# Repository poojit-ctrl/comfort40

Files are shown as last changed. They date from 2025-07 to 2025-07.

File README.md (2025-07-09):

# Comfort40

Comfort40 is a compact 40-key mechanical keyboard designed to ditch all the bloat and keep only what matters. It’s got the vibe of minimalism with just enough muscle to handle your everyday typing, coding, shortcut-spamming, and layer-fu. Built for chill, built for speed, built for the desk setups that scream “I know what I’m doing.”



---

## What Even Is This

Comfort40 is a DIY keyboard project for anyone who’s ever looked at a full-size keyboard and thought “nah.” It’s a 40% board, ortholinear (so all the keys line up like a grid), and completely open source. You can build it however you like solder or hotswap, loud clicky switches or silent stealthy ones. It’s your call.

This board runs QMK and VIA, so you can customize literally every key. Layer keys? Macro madness? Tap dance? Yeah, it’s all here. Want a numpad? Put it on a layer. Arrows? You bet. The layout may be tiny but the power is unhinged.

---

## The Vibe

Comfort40 is designed in KiCad, modeled in Fusion 360, and 100% meant to be hacked on. The case is 3D printable, the plate is laser cuttable.
---

## Build Stats

layout → 4x10 grid  
switches → MX-style 
controller → RP2040  
port → USB-C  
pcb → hotswap  
NO RGB THO  
case → printable 
firmware → QMK + VIA

---
| Component | Description | Qty | Estimated Price (USD) | Notes |
|---|---|-----|---|---|
| **PCB** | Custom Comfort40 PCB | 1 | $30.00(after coupon) | From JLCPCB or similar |
| **Microcontroller** | RP2040 | 1 | $2.00 | USB-C |
| **Switches** | MX-compatible mechanical switches | 40  | $20.00 | Gateron|
| **Keycaps** | 40-key ortholinear set | 1 | $23.00 | XDA/DSA works well |
| **Diodes** | 1N4148 | 40  | $3.00 | Through-hole or SMD |
| **Reset Switch** | Tactile momentary switch | 1 | $0.50 | Used for flashing |
| **Hotswap Sockets** | Kailh MX hotswap sockets | 40  | $8.00 | Why not |
| **Plate** | Laser-cut acrylic or FR4 | 1 | $6.00 | DXF included |
| **Case (Top + Bottom)** | 3D printed or resin enclosure | 1 | $18.00 | Print or outsource |
| **Screws/Standoffs** | M3 hardware | 1 set | $2.00 | For mounting everything |
| **USB Cable** | USB-C to USB-A cable | 1 | $4.00 | Any decent one |
| **Rotary Encoder** | EC11 vertical rotary encoder | 1 | $2.00 | Includes push button switch |
| **Knob Cap** | Aluminum or plastic vertical knob | 1 | $1.50 | Press-fit or set screw type |
| **Foam/Dampening** | EVA foam or PE sheet | 1 | ALREADY HAVE IT AT HOME| silencing mod |

---
## Estimated Total: **$120.00 USD**

## Images

## Fully Assembled Render  
| Image | Description |
|---|---|
| fully assembled render | A render straight outta Fusion 360. You’re looking at the full Comfort40 in all its glory, keycaps and all. |

## PCB  
| Image | Description |
|---|---|
| pcb | KiCad PCB layout. Shows the switch footprint grid, MCU spot, USB traces, and that crispy clean diode matrix. |

## Schematic  
| Image | Description |
|---|---|
| schematic | The full wiring brain. Every connection from switch to controller. Diodes, resistors, reset, and the rest. |

## KiCad 3D View  
| Image | Description |
|---|---|
| 3dview | The raw KiCad 3D preview. Check that switch layout and component placement. No case here, just vibes. |

## Hot swappable
| Image | Description |
|---|---|
|  | KLE Layout |

---

## Flashing the Brain

QMK is the default brain of Comfort40. Flash it with QMK Toolbox or VIA Configurator

---

## Who It’s For

- people who like small keyboards  
- people who like building stuff  
- people who hate reaching for arrow keys  
- people who want full power in a tiny square of plastic  
- also people who just want a reason to use their soldering iron again

---

## Licence

MIT

made for comfort not clutter  
zero bloat  
just keys

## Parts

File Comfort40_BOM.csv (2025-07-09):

Component | Description | Qty | Estimated Price (USD) | Notes
PCB | Custom Comfort40 PCB | 1 | 30 | From JLCPCB or similar
Microcontroller | RP2040 | 1 | 2 | USB-C
Switches | MX-compatible mechanical switches | 40 | 20 | Gateron
Keycaps | 40-key ortholinear set | 1 | 23 | XDA/DSA works well
Diodes | 1N4148 | 40 | 3 | Through-hole or SMD
Reset Switch | Tactile momentary switch | 1 | 0.5 | Used for flashing
Hotswap Sockets | Kailh MX hotswap sockets | 40 | 8 | Why not
Plate | Laser-cut acrylic or FR4 | 1 | 6 | DXF included
Case (Top + Bottom) | 3D printed or resin enclosure | 1 | 18 | Print or outsource
Screws/Standoffs | M3 hardware | 1 set | 2 | For mounting everything
USB Cable | USB-C to USB-A cable | 1 | 4 | Any decent one
Rotary Encoder | EC11 vertical rotary encoder | 1 | 2 | Includes push button switch
Knob Cap | Aluminum or plastic vertical knob | 1 | 1.5 | Press-fit or set screw type
Foam/Dampening | EVA foam or PE sheet | 1 | AVAILABLE | Optional silencing mod
 |  |  | $120.00

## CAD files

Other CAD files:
Case(f360 and step)/comfort40final.f3d

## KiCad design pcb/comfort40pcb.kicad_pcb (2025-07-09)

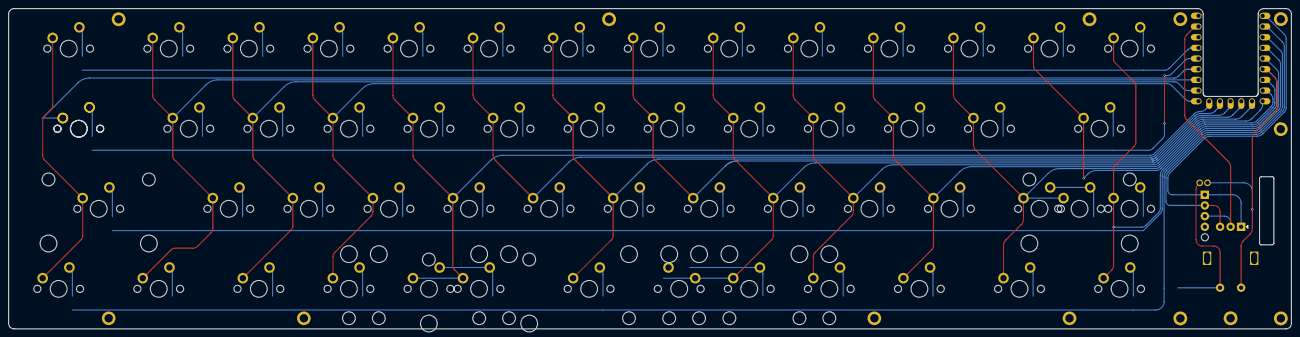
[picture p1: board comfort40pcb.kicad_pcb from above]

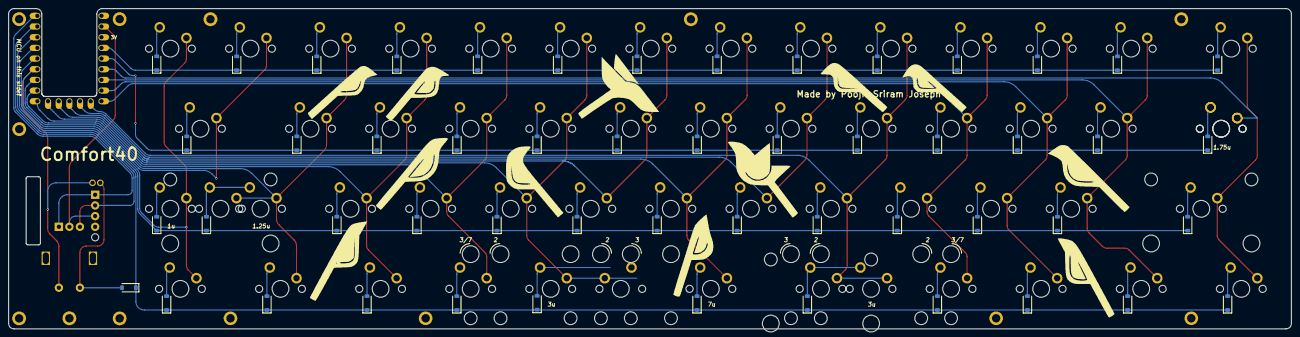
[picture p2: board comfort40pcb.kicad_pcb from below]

Board: 2 copper layers, 305.2 x 76.2 mm, 113 parts (52 on the bottom side), 73 nets.

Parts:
D1, D2, D3, D4, D5, D6, D7, D8, D9, D10, D11, D12, D13, D14, D15, D16, D17, D18, D19, D20, D21, D22, D23, D24, D25, D26, D27, D28, D29, D30, D31, D32, D33, D34, D35, D36, D37, D38, D39, D40, D41, D42, D43, D44, D45, D46, D47, D48, D49, D50, D51, D52: 1N4148W; D_SOD-123
MP: (no value)
SW1: MX150
SW2, SW3#2, SW4, SW5, SW6, SW7, SW8, SW9, SW10, SW11, SW12, SW13, SW14, SW16, SW17, SW18, SW19, SW20, SW21, SW22, SW23, SW24, SW25, SW26, SW29, SW30, SW31, SW32, SW33, SW34, SW35, SW36, SW37, SW38, SW45, SW50: MX100
SW3: Rotary_Encoder_Switch; EVQWGD001
SW15: Stepped; MX175
SW27: MX175
SW28: MX225R; MX225
SW39: 1.25u; MX125
SW40, SW47: 2.25u; MX225
SW41: 1u; MX100
SW42, SW43, SW44, SW51, SW52, SW53: MX125
SW46, SW49: 3u; MX300R
SW48: 7u; MX100
SW54: 2.75u; MX275R
SW55: RotaryEncoder_Switch; RotaryEncoder_Alps_EC11E-Switch_Vertical_H20mm
SW55#2: 1.75u; MX175
SW**: MX200R
SW**#2: MX200R
U1: RP2040-Zero; MCU_rp2040-zero-tht

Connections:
COL0: SW1.2 (Row), SW15.2 (Row), SW28.2 (Row), SW42.2 (Row), SW55#2.2
COL1: SW2.2 (Row), SW16.2 (Row), SW29.2 (Row), SW43.2 (Row)
COL2: SW3#2.2 (Row), SW17.2 (Row), SW30.2 (Row), SW44.2 (Row), U1.15
COL3: SW4.2 (Row), SW18.2 (Row), SW31.2 (Row), SW45.2 (Row), U1.14
COL4: SW5.2 (Row), SW19.2 (Row), SW32.2 (Row), SW46.2 (Row), SW47.2 (Row), U1.13
COL5: SW6.2 (Row), SW20.2 (Row), SW33.2 (Row), U1.12
COL6: SW7.2 (Row), SW21.2 (Row), SW34.2 (Row), SW48.2 (Row), U1.11
COL7: SW8.2 (Row), SW22.2 (Row), SW35.2 (Row), U1.10
COL8: SW9.2 (Row), SW23.2 (Row), SW36.2 (Row), SW49.2 (Row), SW54.2 (Row), U1.9
COL9: SW10.2 (Row), SW24.2 (Row), SW37.2 (Row), SW50.2 (Row), U1.8
COL10: SW11.2 (Row), SW25.2 (Row), SW38.2 (Row), SW51.2 (Row), U1.7
COL11: SW12.2 (Row), SW26.2 (Row), SW39.2 (Row), SW40.2 (Row), SW52.2 (Row), U1.6
COL12: SW3.S2, SW13.2 (Row), SW27.2 (Row), SW55.S2, U1.5
COL13: SW14.2 (Row), SW41.2 (Row), SW53.2 (Row), U1.4
ENC_CCW: SW3.A, SW55.A
ENC_CW: SW3.B, SW55.B, U1.1
GND: SW3.C, SW55.C
unnamed: D1.2 (A), SW1.1 (Col)
unnamed: D2.2 (A), SW2.1 (Col)
unnamed: D3.2 (A), SW3#2.1 (Col)
unnamed: D4.2 (A), SW4.1 (Col)
unnamed: D5.2 (A), SW5.1 (Col)
unnamed: D6.2 (A), SW6.1 (Col)
unnamed: D7.2 (A), SW7.1 (Col)
unnamed: D8.2 (A), SW8.1 (Col)
unnamed: D9.2 (A), SW9.1 (Col)
unnamed: D10.2 (A), SW10.1 (Col)
unnamed: D11.2 (A), SW11.1 (Col)
unnamed: D12.2 (A), SW12.1 (Col)
unnamed: D13.2 (A), SW13.1 (Col)
unnamed: D14.2 (A), SW14.1 (Col)
unnamed: D15.2 (A), SW15.1 (Col), SW55#2.1
unnamed: D16.2 (A), SW16.1 (Col)
unnamed: D17.2 (A), SW17.1 (Col)
unnamed: D18.2 (A), SW18.1 (Col)
unnamed: D19.2 (A), SW19.1 (Col)
unnamed: D20.2 (A), SW20.1 (Col)
unnamed: D21.2 (A), SW21.1 (Col)
unnamed: D22.2 (A), SW22.1 (Col)
unnamed: D23.2 (A), SW23.1 (Col)
unnamed: D24.2 (A), SW24.1 (Col)
unnamed: D25.2 (A), SW25.1 (Col)
unnamed: D26.2 (A), SW26.1 (Col)
unnamed: D27.2 (A), SW27.1 (Col)
unnamed: D28.2 (A), SW28.1 (Col)
unnamed: D29.2 (A), SW29.1 (Col)
unnamed: D30.2 (A), SW30.1 (Col)
unnamed: D31.2 (A), SW31.1 (Col)
unnamed: D32.2 (A), SW32.1 (Col)
unnamed: D33.2 (A), SW33.1 (Col)
unnamed: D34.2 (A), SW34.1 (Col)
unnamed: D35.2 (A), SW35.1 (Col)
unnamed: D36.2 (A), SW36.1 (Col)
unnamed: D37.2 (A), SW37.1 (Col)
unnamed: D38.2 (A), SW38.1 (Col)
unnamed: D39.2 (A), SW39.1 (Col), SW40.1 (Col)
unnamed: D40.2 (A), SW3.S1, SW55.S1
unnamed: D41.2 (A), SW41.1 (Col)
unnamed: D42.2 (A), SW53.1 (Col)
unnamed: D43.2 (A), SW52.1 (Col)
unnamed: D44.2 (A), SW51.1 (Col)
unnamed: D45.2 (A), SW50.1 (Col)
unnamed: D46.2 (A), SW49.1 (Col), SW54.1 (Col)
unnamed: D47.2 (A), SW48.1 (Col)
unnamed: D48.2 (A), SW46.1 (Col), SW47.1 (Col)
unnamed: D49.2 (A), SW45.1 (Col)
unnamed: D50.2 (A), SW44.1 (Col)
unnamed: D51.2 (A), SW43.1 (Col)
unnamed: D52.2 (A), SW42.1 (Col)
ROW0: D1.1 (K), D2.1 (K), D3.1 (K), D4.1 (K), D5.1 (K), D6.1 (K), D7.1 (K), D8.1 (K), D9.1 (K), D10.1 (K), D11.1 (K), D12.1 (K), D13.1 (K), D14.1 (K)
ROW1: D15.1 (K), D16.1 (K), D17.1 (K), D18.1 (K), D19.1 (K), D20.1 (K), D21.1 (K), D22.1 (K), D23.1 (K), D24.1 (K), D25.1 (K), D26.1 (K), D27.1 (K)
ROW2: D28.1 (K), D29.1 (K), D30.1 (K), D31.1 (K), D32.1 (K), D33.1 (K), D34.1 (K), D35.1 (K), D36.1 (K), D37.1 (K), D38.1 (K), D39.1 (K), D41.1 (K), U1.3
ROW3: D40.1 (K), D42.1 (K), D43.1 (K), D44.1 (K), D45.1 (K), D46.1 (K), D47.1 (K), D48.1 (K), D49.1 (K), D50.1 (K), D51.1 (K), D52.1 (K), U1.2

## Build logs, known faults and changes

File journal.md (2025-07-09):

# comfort40 journal  
a log of everything from brain fog to actual progress  

---

## July 1  
**Task**: Starting the schematic  
Sat down and opened KiCad for the first time on this project  
Added footprints for diodes and switches  
Googled “how to do schematic layout properly” more than once  
Started basic matrix planning but got distracted halfway  

**Time Spent**: 0.8 hrs  

| Image | Description |
|---|---|
|  | Initial schematic work in KiCad |

---

## July 2  
**Task**: Schematic cleanup and adding components  
Realized the diode directions were all over the place  
Fixed them and added reset button and rotary encoder footprints  
Spent more time figuring out encoder wiring than expected  

**Time Spent**: 1.2 hrs  

| Image | Description |
|---|---|
|  | Updated schematic with rotary encoder |

---

## July 3  
**Task**: PCB routing  
Did almost all the routing in one session  
Tried using the autorouter then gave up and went manual  
Double-checked spacing for Kailh sockets and encoder clearance  

**Time Spent**: 2.0 hrs  

| Image | Description |
|---|---|
|  | Final routed board in PCB editor |

---

## July 4  
**Task**: Part selection  
Browsed through parts for like three hours  
Shortlisted switches and keycaps  
Tested encoder sizes against the board  
Made a spreadsheet for the BOM  

**Time Spent**: 1.5 hrs  

| Image | Description |
|---|---|
|  | BOM draft and part selection progress |

---

## July 5  
**Task**: MCU and firmware planning  
Decided on rp2040 for compact form factor  
Verified that the encoder and matrix pin assignments were valid  
Sketched out rough layout plan for QMK config  

**Time Spent**: 1.0 hrs  

| Image | Description |
|---|---|
|   | Pinout notes and QMK planning sketch |

---

## July 6  
**Task**: Starting the 3D model  
Imported plate from KiCad into Fusion  
Started blocking out the top shell  
Tried 3 different plate mounting ideas  
Settled on using standoffs and snap fit  

**Time Spent**: 2.0 hrs  

| Image | Description |
|---|---|
| 3drender | Fusion model of top case beginning |

---

## July 7  
**Task**: Modeling the bottom shell  
Finished standoffs and modeled cutout for encoder  
Totally forgot to leave space for the USB port  
Fixed wall thickness and made the case printable  

**Time Spent**: 2.0 hrs  

| Image | Description |
|---|---|
|  | Bottom case in Fusion with encoder slot |

---

## July 8  
**Task**: Detailing the model  
Refined corner radius and added fillets  
Did a dry run to align the plate with the case  
Added inner ledge for plate support  
Rendered a high-res preview for the log  

**Time Spent**: 2.5 hrs  

| Image | Description |
|---|---|
|  | Final case design and render preview |

---

## July 9  
**Task**: File exports and measurements  
Exported STL files for both case halves  
Did a full clearance check on encoder and switch positions  
Made sure screw holes lined up with standoffs  

**Time Spent**: 1.5 hrs  

---

## July 10  
**Task**: Final checks and summary  
Went through schematic PCB and model once more  
Tested the VIA layout and generated JSON  
Saved everything to repo and backed it up  

**Time Spent**: 1.0 hrs  

---

## Total Time Logged  
**~14.5 hours**
